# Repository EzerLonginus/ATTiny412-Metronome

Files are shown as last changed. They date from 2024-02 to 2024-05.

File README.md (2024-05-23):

# ATTiny412 Metronome
ATTiny412 metronome build
This board is a simple metronome using the ATTiny 412 chip.  The interface includes two push buttons, one rotaty encorder with push button, I2C OLED breakout, and headphone amplifier.  The unit can be powered via a USB-C connector, and has a 6.35mm headphone jack for audio output.
There is also a breakout pins for the UPDI programming, and an additional pin out for the PA3 pin if an external clock source is not used.
The switch button footprints are to allow for either the 12mm or 6mm tactile push buttons.

## Purpose
I pretty much wanted an execuse to play around with the ATTiny Series 1 chips, and wanted to build a fairly simple project that would utilize some of the functionality of the chip.  My original intention was to try to build a fairly functional metronome for as little as possible in parts costs.  There are definitely some corners I could have cut further, but in the end I'm mostly just building it for me, so I don't have to go too wild on cost savings.  That said, I may end up revisiting this project and design this for production.  
Having a rotary encoder with a push button, two additional buttons, a headphone amp, and an I2C breakout does lend itself to other projects besides metronomes (obviously).  So this project may also end up being a testing bed for some other audio related projects I have in mind.

## Schematic
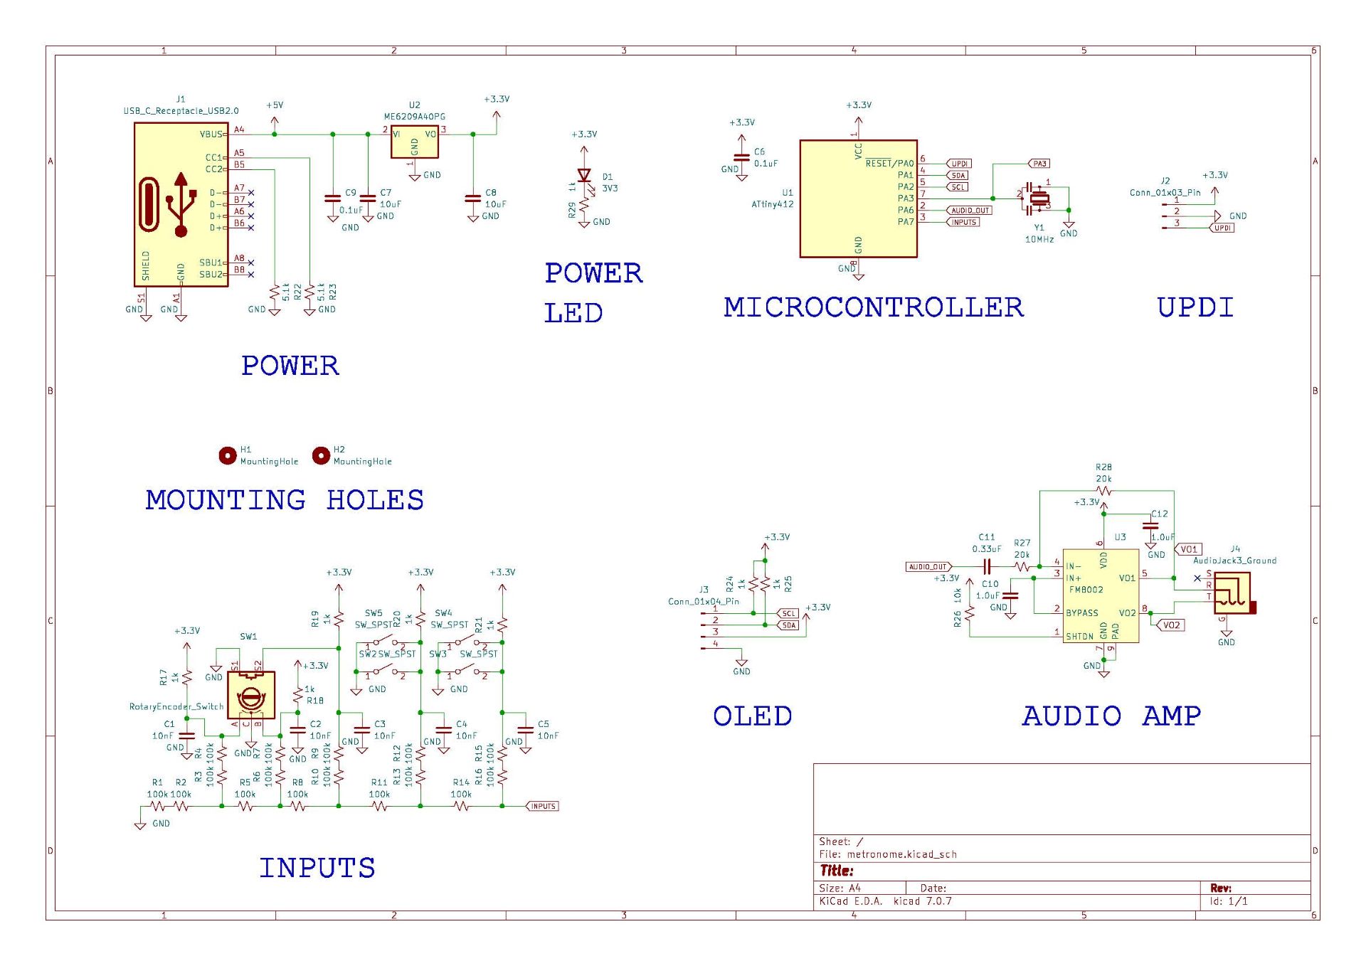
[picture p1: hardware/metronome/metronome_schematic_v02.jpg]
Metronome Schematic


## Layout
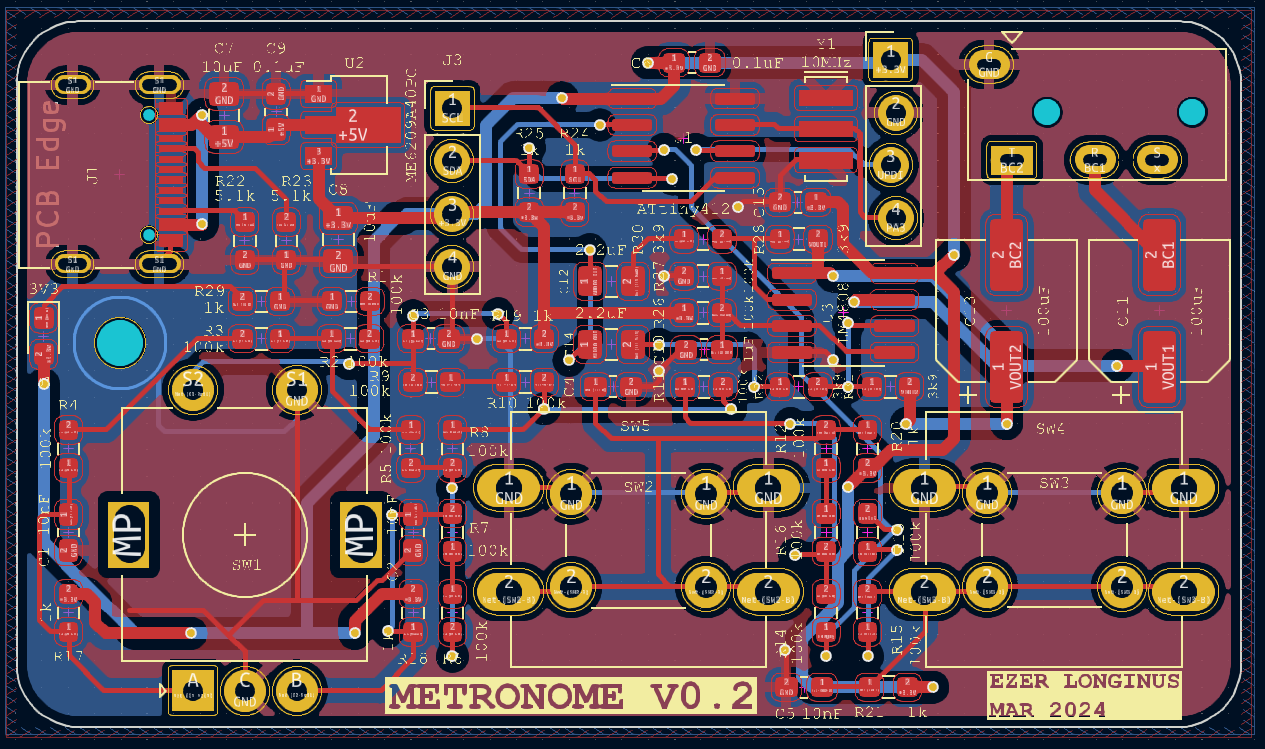
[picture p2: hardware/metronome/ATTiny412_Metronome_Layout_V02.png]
Metronome Layout


## Updates & Fixes
### Version 2
* Changed out headphone amplilfier to LM4808
* Fixed 6.35mm headphone jack footprint
* Added pinout for PA3
* Staggered holes for UPDI for less permananet uploading
* Removed a mounting hole to allow for the DC blocking capacitors



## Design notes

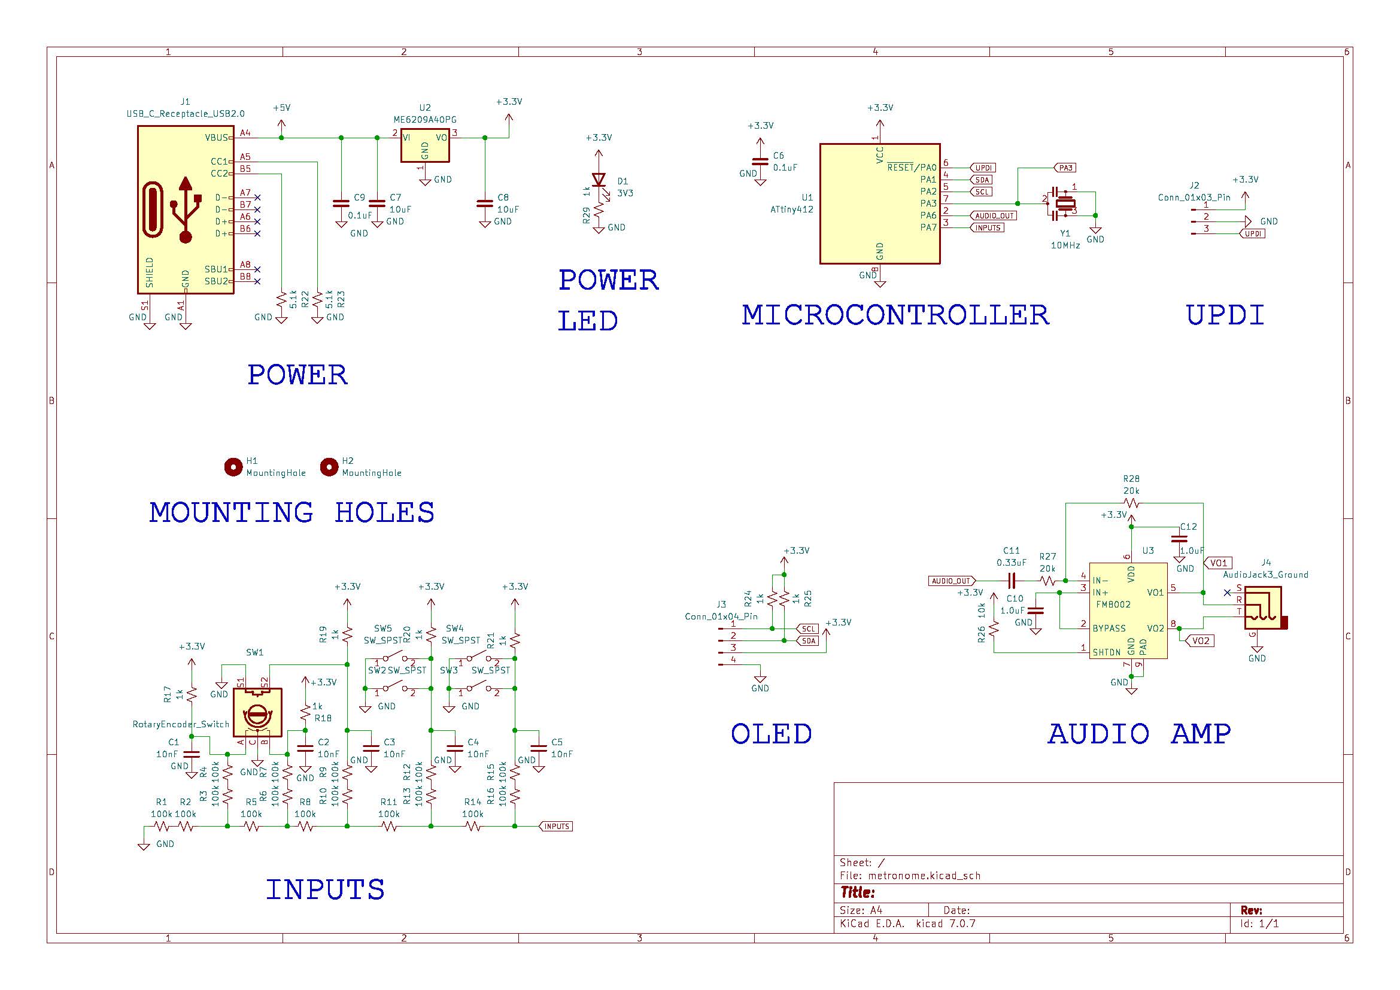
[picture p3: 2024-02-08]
hardware/metronome/metronome_schematic_v0.jpg

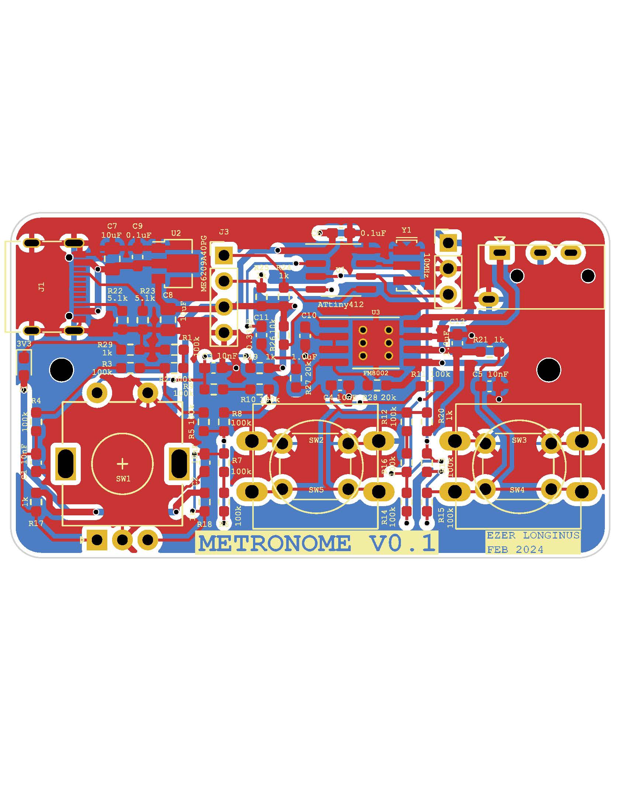
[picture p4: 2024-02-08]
hardware/metronome/metronome_layout_v0.jpg

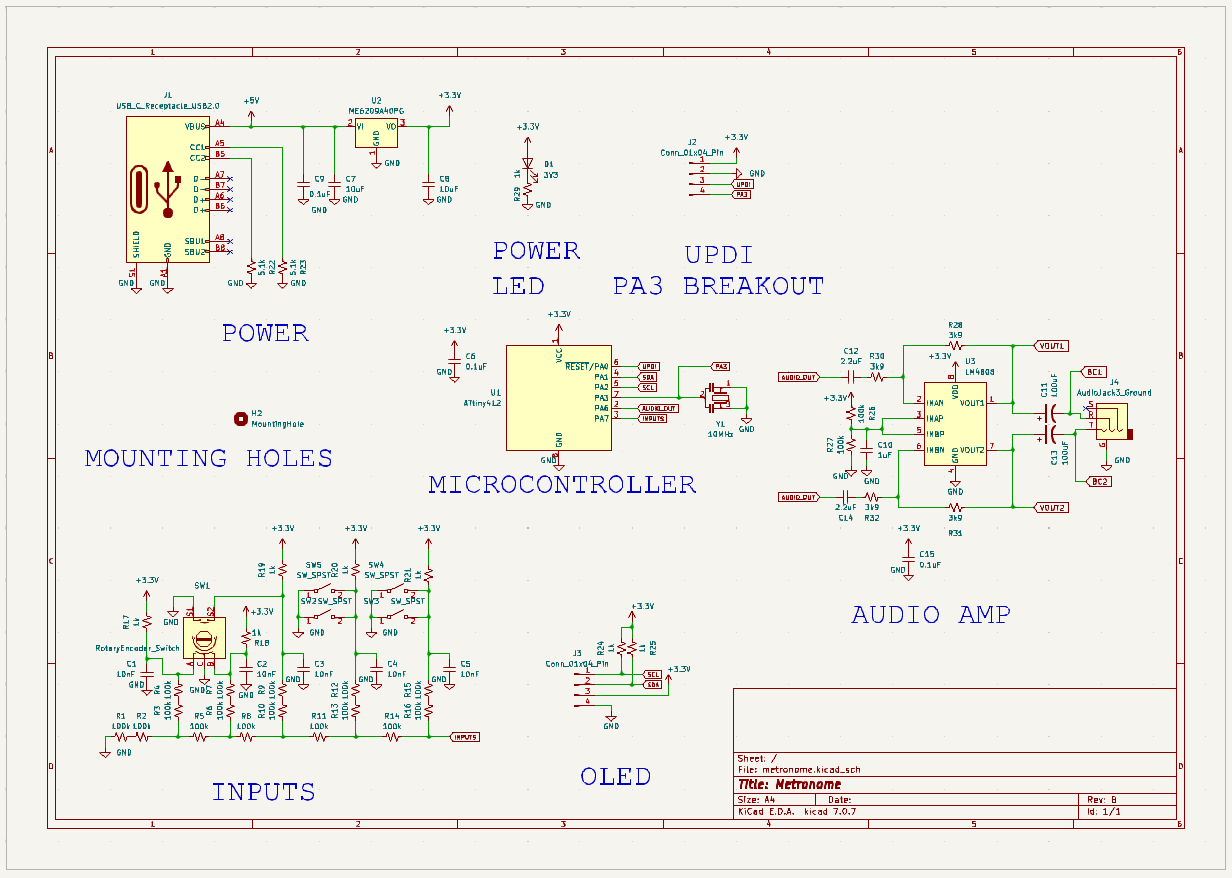
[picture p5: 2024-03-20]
hardware/metronome/ATTIny412_Metronome_Schematic_V02.png

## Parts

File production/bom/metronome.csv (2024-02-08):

Id | Designator | Footprint | Quantity | Designation | Supplier and ref
1 | J4 | Jack_3.5mm_PJ320E_Horizontal | 1 | AudioJack3_Ground
2 | U3 | SOP-8-1EP_4.57x4.57mm_P1.27mm_EP4.57x4.45mm_ThermalVias | 1 | FM8002
3 | D1 | LED_0603_1608Metric_Pad1.05x0.95mm_HandSolder | 1 | 3V3
4 | R29,R25,R24,R21,R20,R19,R18,R17 | R_0603_1608Metric_Pad0.98x0.95mm_HandSolder | 8 | 1k
5 | H2,H1 | MountingHole_2.2mm_M2 | 2 | MountingHole
6 | SW5,SW4 | SW_PUSH-12mm | 2 | SW_SPST
7 | J3 | PinHeader_1x04_P2.54mm_Vertical | 1 | Conn_01x04_Pin
8 | Y1 | 4.5mm_x_2.0mm_MurataElectronics_3Pin_Resonator | 1 | 10MHz
9 | U2 | SOT-89-3 | 1 | ME6209A40PG
10 | U1 | SOIC-8_3.9x4.9mm_P1.27mm | 1 | ATtiny412
11 | SW3,SW2 | SW_PUSH_6mm_H4.3mm | 2 | SW_SPST
12 | SW1 | RotaryEncoder_Alps_EC11E-Switch_Vertical_H20mm | 1 | RotaryEncoder_Switch
13 | R28,R27 | R_0603_1608Metric_Pad0.98x0.95mm_HandSolder | 2 | 20k
14 | R26 | R_0603_1608Metric_Pad0.98x0.95mm_HandSolder | 1 | 10k
15 | R23,R22 | R_0603_1608Metric_Pad0.98x0.95mm_HandSolder | 2 | 5.1k
16 | R16,R15,R14,R13,R12,R11,R10,R9,R8,R7,R6,R5,R4,R3,R2,R1 | R_0603_1608Metric_Pad0.98x0.95mm_HandSolder | 16 | 100k
17 | J2 | PinHeader_1x03_P2.54mm_Vertical | 1 | Conn_01x03_Pin
18 | J1 | USB_C_Receptacle_Palconn_UTC16-G | 1 | USB_C_Receptacle_USB2.0
19 | C12,C10 | C_0603_1608Metric_Pad1.08x0.95mm_HandSolder | 2 | 1.0uF
20 | C11 | C_0603_1608Metric_Pad1.08x0.95mm_HandSolder | 1 | 0.33uF
21 | C9,C6 | C_0603_1608Metric_Pad1.08x0.95mm_HandSolder | 2 | 0.1uF
22 | C8,C7 | C_0805_2012Metric_Pad1.18x1.45mm_HandSolder | 2 | 10uF
23 | C5,C4,C3,C2,C1 | C_0603_1608Metric_Pad1.08x0.95mm_HandSolder | 5 | 10nF

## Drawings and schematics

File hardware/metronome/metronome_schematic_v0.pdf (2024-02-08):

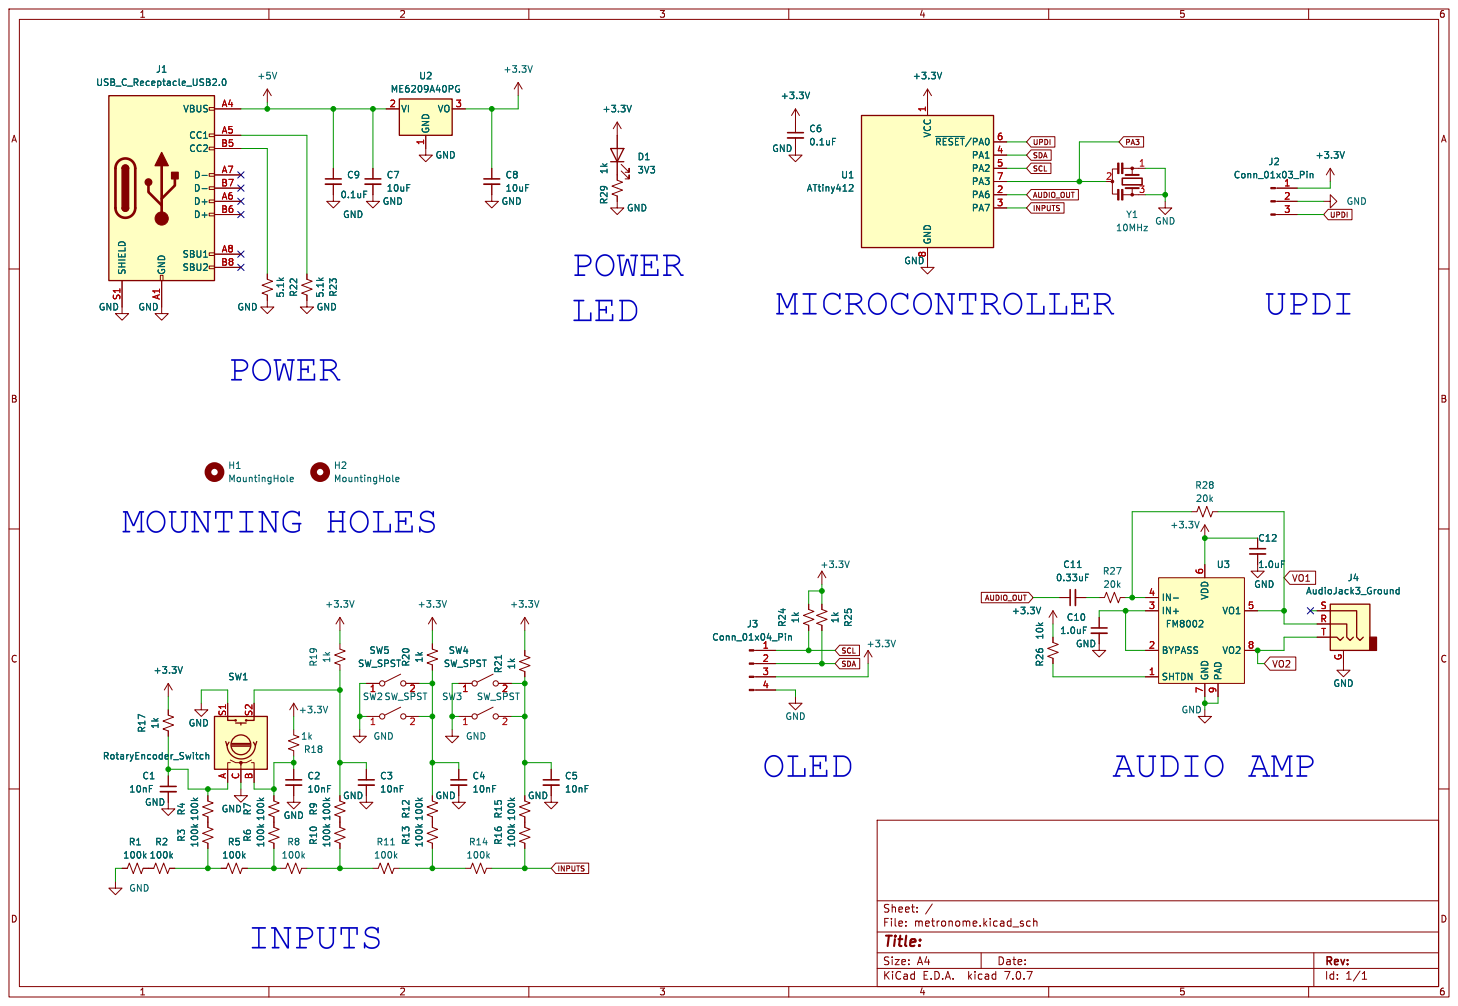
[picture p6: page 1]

Id: 1/1 Title: File: metronome.kicad_sch Sheet: / R14

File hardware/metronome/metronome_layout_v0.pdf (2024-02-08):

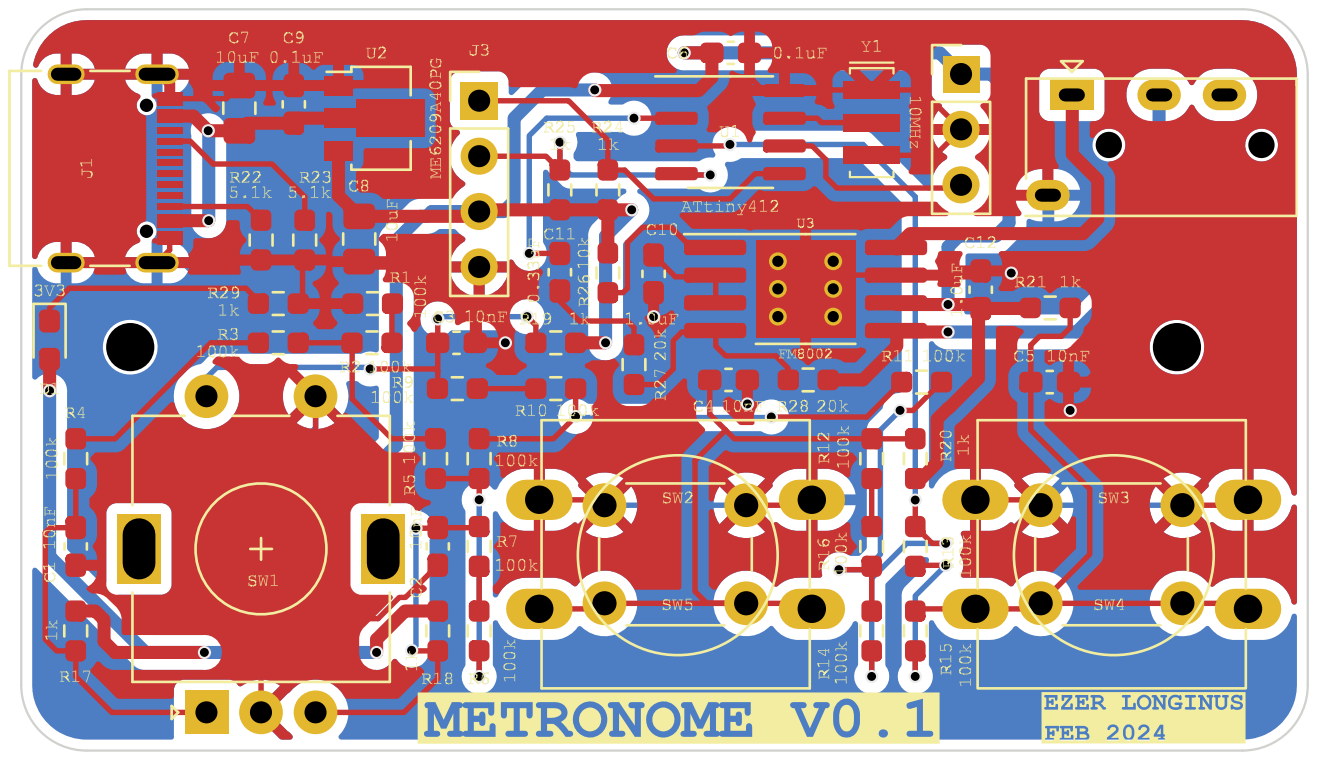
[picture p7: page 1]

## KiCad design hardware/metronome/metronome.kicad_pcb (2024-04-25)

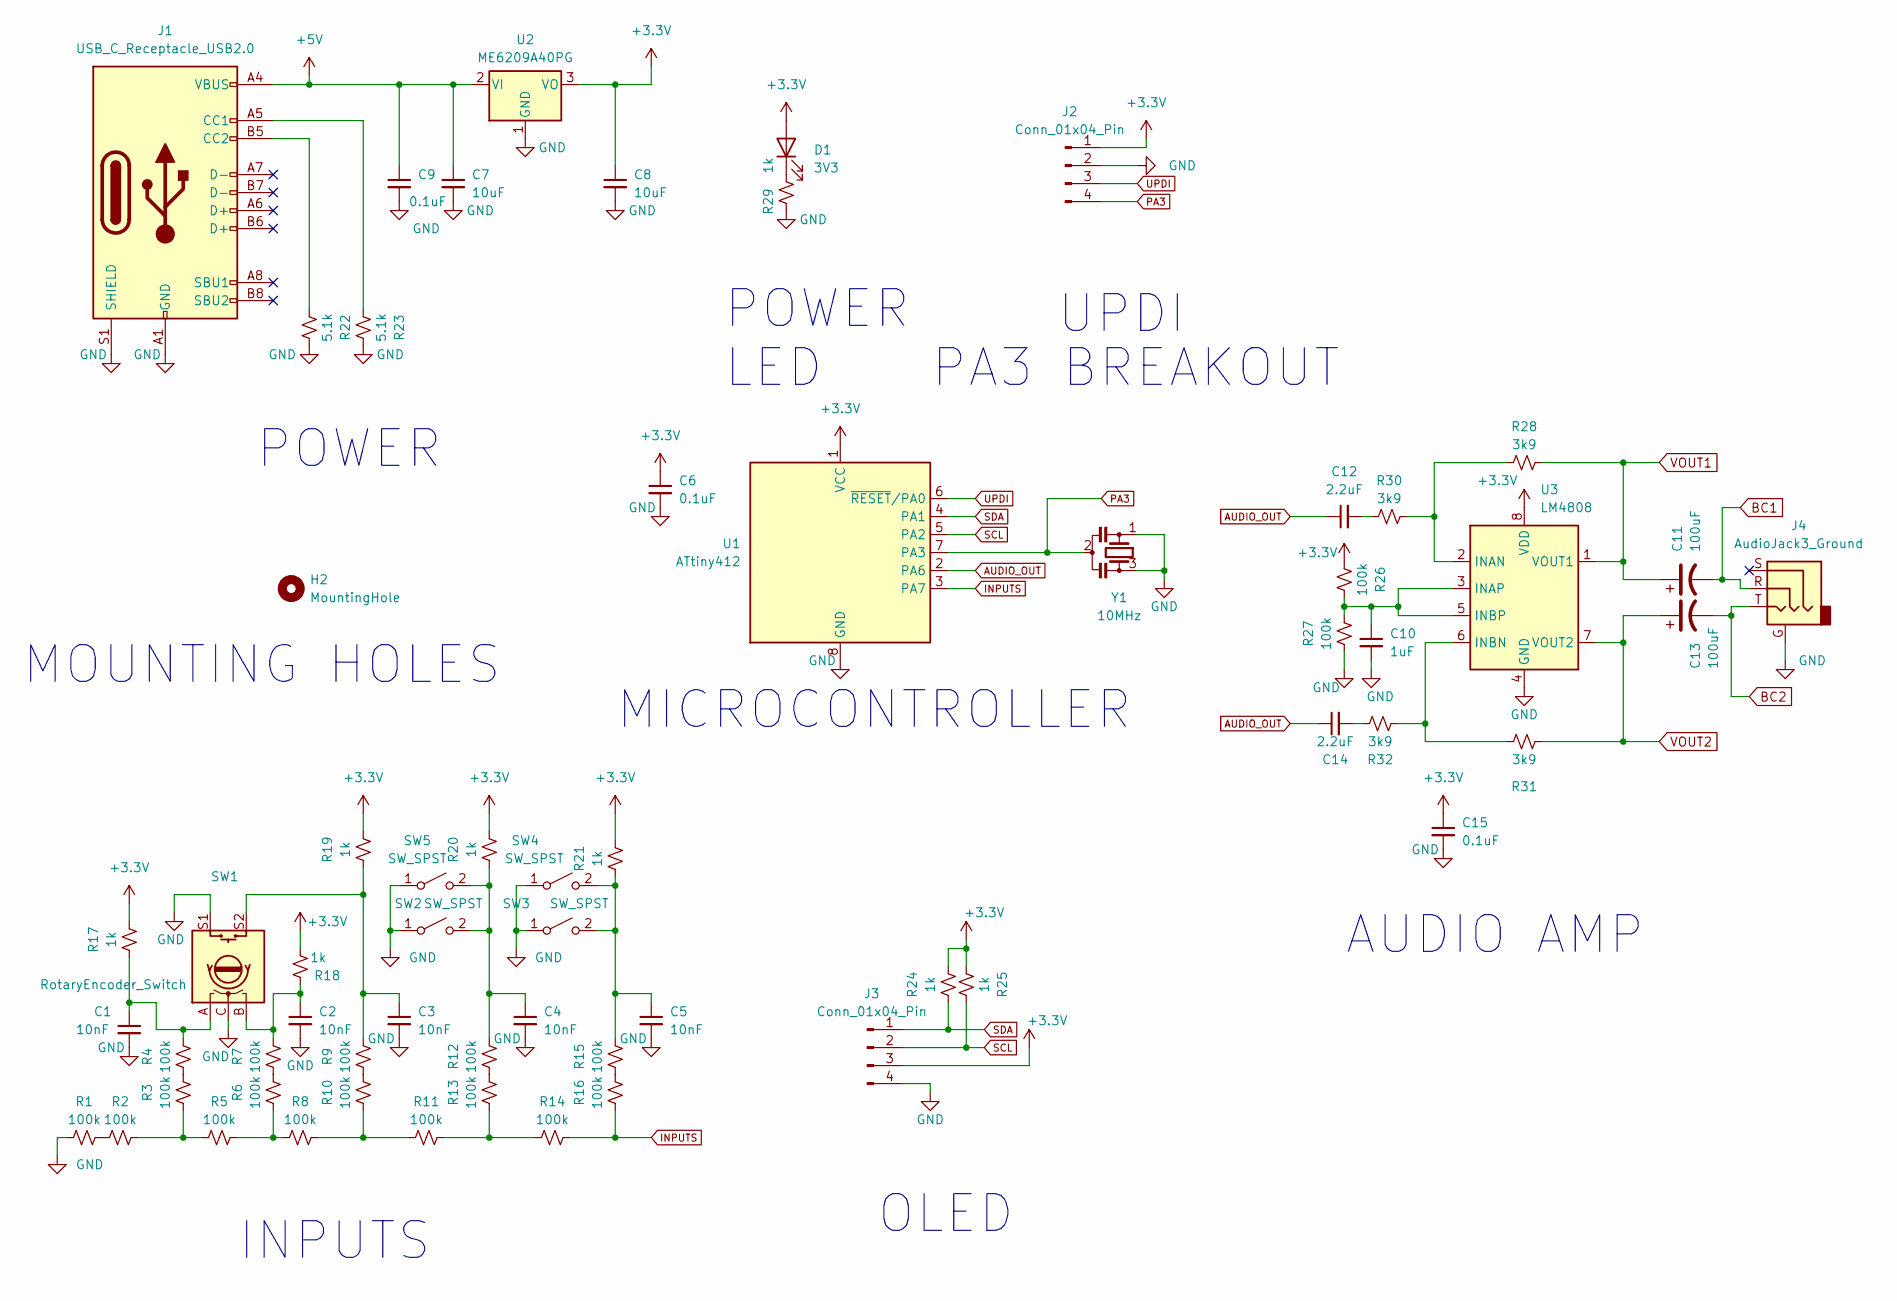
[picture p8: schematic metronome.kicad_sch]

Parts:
C1, C2, C3, C4, C5: 10nF; C_0603_1608Metric_Pad1.08x0.95mm_HandSolder
C6, C9, C15: 0.1uF; C_0603_1608Metric_Pad1.08x0.95mm_HandSolder
C7, C8: 10uF; C_0805_2012Metric_Pad1.18x1.45mm_HandSolder
C10: 1uF; C_0603_1608Metric_Pad1.08x0.95mm_HandSolder
C11, C13: 100uF; CP_Elec_6.3x5.4_Nichicon
C12, C14: 2.2uF; C_0805_2012Metric_Pad1.18x1.45mm_HandSolder
D1: 3V3; LED_0603_1608Metric_Pad1.05x0.95mm_HandSolder
H2: MountingHole; MountingHole_2.2mm_M2
J1: USB_C_Receptacle_USB2.0; USB_C_Receptacle_Palconn_UTC16-G
J2: Conn_01x04_Pin; 1x4_2.54mm_pin_staggered
J3: Conn_01x04_Pin; PinHeader_1x04_P2.54mm_Vertical
J4: AudioJack3_Ground; 6.35mm headphone jack PJ-611A
R1, R2, R3, R4, R5, R6, R7, R8, R9, R10, R11, R12, R13, R14, R15, R16, R26, R27: 100k; R_0603_1608Metric_Pad0.98x0.95mm_HandSolder
R17, R18, R19, R20, R21, R24, R25, R29: 1k; R_0603_1608Metric_Pad0.98x0.95mm_HandSolder
R22, R23: 5.1k; R_0603_1608Metric_Pad0.98x0.95mm_HandSolder
R28, R30, R31, R32: 3k9; R_0603_1608Metric_Pad0.98x0.95mm_HandSolder
SW1: RotaryEncoder_Switch; RotaryEncoder_Alps_EC11E-Switch_Vertical_H20mm
SW2, SW3: SW_SPST; SW_PUSH_6mm
SW4, SW5: SW_SPST; SW_PUSH_12mm
U1: ATtiny412; SOIC-8_3.9x4.9mm_P1.27mm
U2: ME6209A40PG; SOT-89-3
U3: LM4808; SOIC-8_3.9x4.9mm_P1.27mm
Y1: 10MHz; 4.5mm_x_2.0mm_MurataElectronics_3Pin_Resonator

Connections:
+3.3V: C6.1, C8.1, C15.1, D1.2 (A), J2.1, J3.3, R17.2, R18.2, R19.2, R20.2, R21.2, R24.2, R25.2, R26.1, U1.1 (VCC), U2.3 (VO), U3.8 (VDD)
+5V: C7.1, C9.1, J1.A4 (VBUS), J1.A9 (VBUS), J1.B4 (VBUS), J1.B9 (VBUS), U2.2 (VI)
AUDIO_OUT: C12.1, C14.1, U1.2 (PA6)
BC1: C11.2, J4.R
BC2: C13.2, J4.T
GND: C1.2, C2.2, C3.2, C4.2, C5.2, C6.2, C7.2, C8.2, C9.2, C10.2, C15.2, J1.A1 (GND), J1.A12 (GND), J1.B1 (GND), J1.B12 (GND), J1.S1 (SHIELD), J2.2, J3.4, J4.G, R1.1, R22.2, R23.1, R27.2, R29.1, SW1.C, SW1.S1, SW2.1 (A), SW3.1 (A), SW4.1 (A), SW5.1 (A), U1.8 (GND), U2.1 (GND), U3.4 (GND), Y1.1, Y1.3
INPUTS: R14.1, R16.2, U1.3 (PA7)
unnamed: C1.1, R4.1, R17.1, SW1.A
unnamed: C2.1, R7.2, R18.1, SW1.B
unnamed: C3.1, R9.2, R19.1, SW1.S2
unnamed: C12.2, R30.1
unnamed: C14.2, R32.1
unnamed: D1.1 (K), R29.2
unnamed: J1.A5 (CC1), R23.2
unnamed: J1.B5 (CC2), R22.1
unnamed: R1.2, R2.2
unnamed: R2.1, R3.1, R5.1
unnamed: R3.2, R4.2
unnamed: R5.2, R6.2, R8.2
unnamed: R6.1, R7.1
unnamed: R9.1, R10.1
unnamed: R8.1, R10.2, R11.2
unnamed: R11.1, R13.2, R14.2
unnamed: R12.1, R13.1
unnamed: R15.1, R16.1
unnamed: C4.1, R12.2, R20.1, SW2.2 (B), SW5.2 (B)
unnamed: C5.1, R15.2, R21.1, SW3.2 (B), SW4.2 (B)
unnamed: R28.1, R30.2, U3.2 (INAN)
unnamed: C10.1, R26.2, R27.1, U3.3 (INAP), U3.5 (INBP)
unnamed: R31.1, R32.2, U3.6 (INBN)
PA3: J2.4, U1.7 (PA3), Y1.2
SCL: J3.2, R25.1, U1.5 (PA2)
SDA: J3.1, R24.1, U1.4 (PA1)
UPDI: J2.3, U1.6 (~RESET/PA0)
VOUT1: C11.1, R28.2, U3.1 (VOUT1)
VOUT2: C13.1, R31.2, U3.7 (VOUT2)

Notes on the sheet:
OLED
PA3 BREAKOUT
UPDI
POWER LED
AUDIO AMP
MOUNTING HOLES
INPUTS
POWER
MICROCONTROLLER

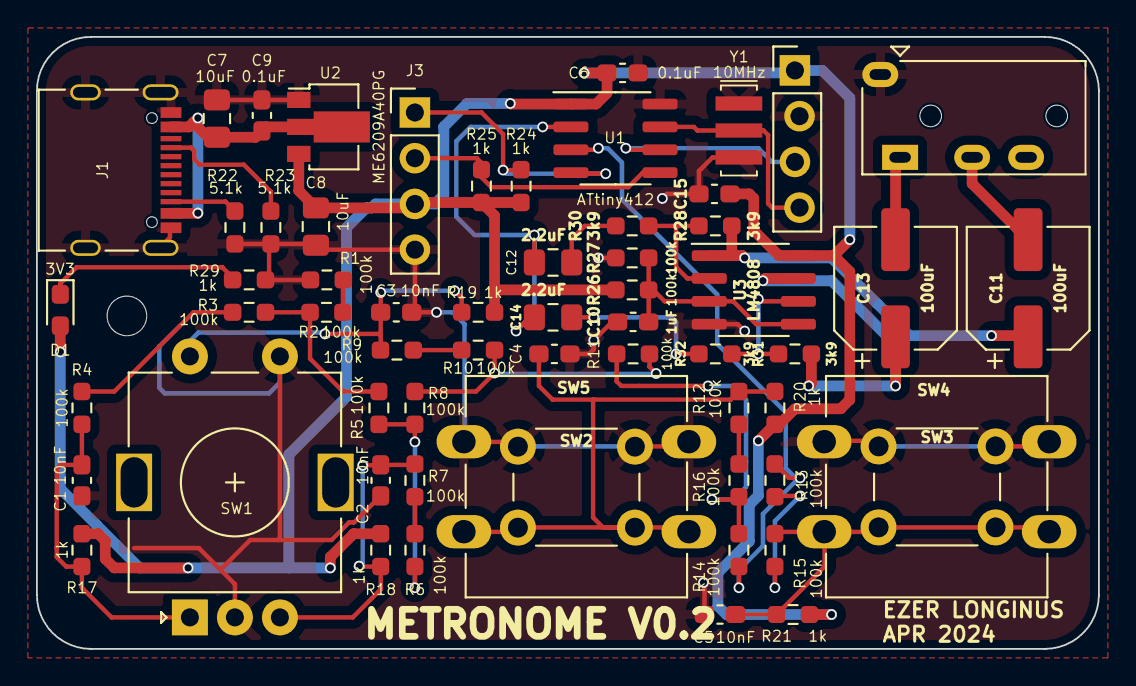
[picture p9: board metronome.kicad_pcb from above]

Board: 2 copper layers, 59.0 x 34.0 mm, 62 parts (0 on the bottom side), 36 nets.

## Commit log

2024-02-08 initial pcb design
    [metronome-B_Cu.gbr, metronome-B_Mask.gbr, metronome-B_Paste.gbr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]
2024-02-08 gerber file zipped
    [metronome.csv]
2024-02-08 removed extraneous files
    [metronome.kicad_pcb]
2024-03-20 Version 02
    [metronome-B_Cu.gbr, metronome-B_Mask.gbr, metronome-B_Paste.gbr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]
2024-03-20 Fixed Gerber Files Ommissions
    [metronome-B_Cu.gbr, metronome-B_Mask.gbr, metronome-B_Paste.gbr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]
2024-04-25 pin swap
    [metronome-B_Cu.gbr, metronome-B_Mask.gbr, metronome-B_Paste.gbr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]
2024-05-23 reduce schematic image
